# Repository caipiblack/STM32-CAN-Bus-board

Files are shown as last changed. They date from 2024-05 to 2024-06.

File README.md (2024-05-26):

STM32-CAN-Bus-board
-------------------

CAN Bus shield with external power supply (12V/24V) for NUCLEO-L432KC board.

All the pins of the NUCLEO-L432KC board are available on the connectors of the shield.

The available pins provide many peripherals (ADC, SPI, I2C, GPIO and more) that can be used for many projects (IOT sensors, security sensors, automation...)

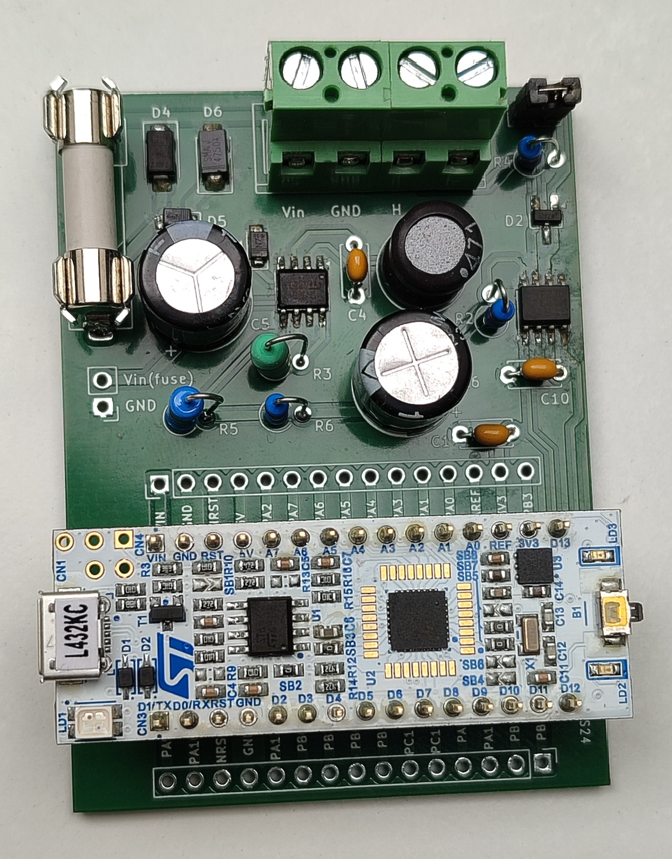
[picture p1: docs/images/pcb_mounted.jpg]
PCB Mounted


# Hardware

This part describe how the schematic was made, how to mount the PCB and how to test it.

**IMPORTANT: This shield require some modifications on the Nucleo board to works (due to external supply) (see after)**

## Kicad project

The Kicad project as been created with the version 8.0.1 of Kicad.

Most of the symbols and footprints comes from the default libraries.

The custom footprints are stored in the `custom` folder near the Kicad project.

Setup Kicad on Ubuntu 24.04:

```
sudo add-apt-repository ppa:kicad/kicad-8.0-releases
sudo apt update
sudo apt install kicad
```

The last production files are stored in the directory [hardware/rev_a/fab](hardware/rev_a/fab).

## Configuration of the NUCLEO-L432KC board

Some modifications are required to be able to power the Nucleo board from external 3V3 regulator (provided by the shield):
- Remove the jumper!
- Remove SB9.
- Remove SB14.

After these changes:
- The 3V3 power for the STM32 will be provided by "external power source" (the shield).
- The debug/flash side of Nucleo board will not be powered by the "external power source" (the shield).
- To flash or debug the Nucleo board, the Nucleo board must be connected by USB to the computer (The St-Link chip will be powered by 5V>3V regulator in the Nucleo board) AND the 3V3 power must be supplied by the shield (to power the STM32 chip).

## PCB mounting instructions

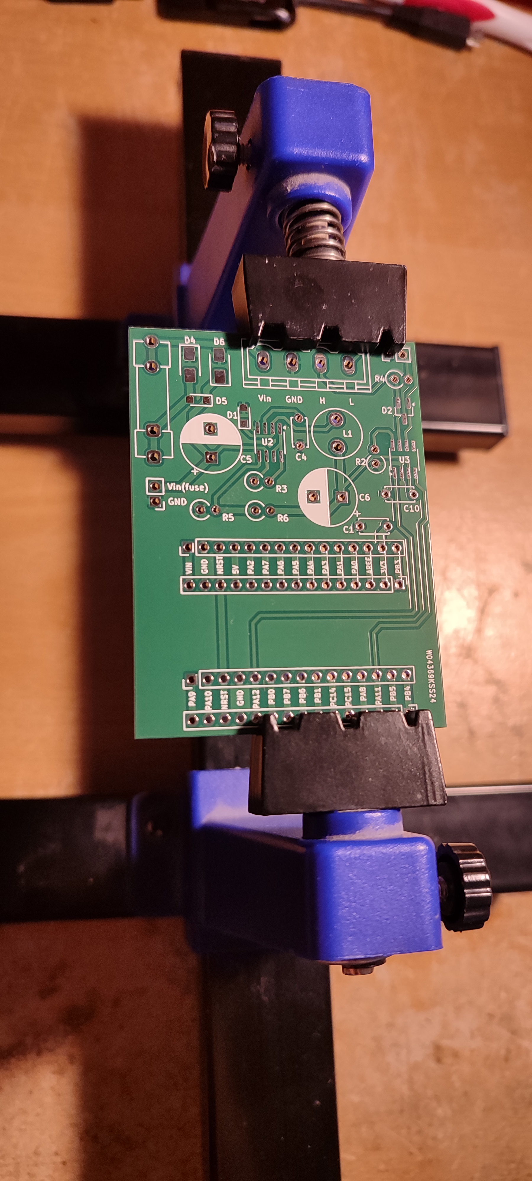
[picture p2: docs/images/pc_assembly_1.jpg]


Mount the components on the board:
1. Take the PCB and fix it to the table.
2. Put solder past on all CMS pads.
3. Configure your hot air machine with something like this:
- Speed: 3/8.
- Temperature: 300°C.
4. Solder the CMS components in this order: D4, D6, D1, D5, D2, U2, U3.
5. Solder the other components in this order: C1, C10, C4, R4, R2, R6, R3, R5, F1, Jumper, C6, C5, L1.
6. Mount the `NUCLEO-L432KC` board in the headers and solder the headers to the PCB (Doing it like this prevent issues with headers that are not perfectly vertical or parallel).
7. Remove the nucleo board from the soldered headers.

## PCB testing instructions

Testing instructions:
- Remove the `NUCLEO-L432KC` board from the headers.
- Power on the board with laboratory power supply configured at 12V with current limited to 50mA.
  - At this point the power consumption (on 12V line) should be less than 10mA.
  - Measure the voltage in the 3V3 pin and check that the voltage is around 3.3V.
- If the previous tests pass, turn off the power and plug the `NUCLEO-L432KC` board in the headers then turn on the power.
  - At this point the power consumption (on 12V line) should be less than 10mA.
- If the previous tests pass, connect the `NUCLEO-L432KC` board to the computer and flash it with the template project.
- Test the CAN interface:
  - Plug a USB<>CAN device from a Linux computer to the board.
  - On the computer, execute these commands:
```
sudo apt-get install can-utils
sudo modprobe vcan
sudo ip link add dev can0 type vcan
sudo ip link set up can0 type can bitrate 250000
candump -td -a can0
```
  - Reset the board
  - On the `candump` you should see something like this:
```
 (000.000000)  can0  71D   [1]  00                        '.'
```

# Software

This repository comes with a demo software in the `software` directory: This software act like a CANopen node and permits to control the LED of the `NUCLEO-L432KC` board.

This guide also describe how to create a project from scratch for the `STM32-CAN-Bus-board` board.

The LED can be controlled by writing in the object at index `0x6001`. (See examples at `CANopenLinux` section).

## Tools setup

1. Download and install `STM32CubeIDE` from [here](https://www.st.com/en/development-tools/stm32cubeide.html)
2. (Optional) Download and install `STM32CubeProg` from [here](https://www.st.com/en/development-tools/stm32cubeprog.html). (This tool can be used to only flash the `NUCLEO-L432KC` board without the IDE)

### Compatibility issues of STM32CubeIDE with Ubuntu 24.04

There are issues with `STM32CubeIDE` on `Ubuntu 24.04` because it has a dependecy to `libncurses5` and this is not available with this version of Ubuntu.

This dependency is required by the `arm-none-eabi-gdb` provided by ST.

To resolve the problem:
- Install the generic linux version of `STM32CubeIDE` instead of the version from `.deb` (as it will not check the dependency).
- Install `arm-none-eabi-gdb` or `gdb-multiarch` and create a link to provide `arm-none-eabi-gdb`:
```
sudo apt install gdb-multiarch
sudo ln -s /usr/bin/gdb-multiarch /usr/bin/arm-none-eabi-gdb
```
- In your project configuration `Project Properties -> C/C++ Build -> Environment -> PATH` add `/usr/bin` at the first place to use `arm-none-eabi-gdb` provided by `/usr/bin` instead of ST directories.

## Create a project from scratch

Base project creation:
1. Open `STM32CubeIDE`.
2. Press `File > New > STM32 Project`.
3. Press `Board Selector`.
4. Search `Commercial Part Number` with `NUCLEO-L432KC`, then select it and press Next
5. Specify the `Project Name` and `Location`, then press `Finish`.
6. Configure the peripheral in defaults state and open the configuration tool (or open `.ioc` file).
7. Change the configuration of `PA0` to `Reset_State` as we don't have MCO clock source when the `NUCLEO-L432KC` is externaly powered from 3V3 (because MCO comes from the St-Link chip and it is not powered in this situation).
8. In `Clock Configuration`:
- Select `System Clock Mux` to use `PLLCLK`
- Select `PLL Source Mux` to `MSI`
- Configure the PLL with `X48` and `/4` to get 48Mhz in SYSCLK and APBs

For the integration of `CANopenNode` stack see the README of [CanOpenSTM32](https://github.com/CANopenNode/CanOpenSTM32):
1. From configuration tool configure the CAN interface:
- Activate `CAN1`
- Activate all the interrupts of `CAN1`
- Enable `Automatic Bus-Off Management`
- Enable `Automatic Wake-Up Mode`
- Enable `Automatic Retransmission`
- Configure the Bit timing parameters, you can use [this generator](http://www.bittiming.can-wiki.info/). The clock for `CAN1` is `APB1` (datasheet). In my case with a clock of 48Mhz and desired bitrate of 250Kbit/s I set:
  - Prescaler: 12
  - Time Quanta in Bit Segment 1: 13 Times
  - Time Quanta in Bit Segment 2: 2 Times
2. From configuration tool configure a timer for `CANopenNode` stack:
- Activate `TIM16`
- Enable the interrupt of `TIM16`
- Configure `TIM16` to get 1ms. Note that `TIM16` use `APB2` clock. In my case with a clock of 48Mhz I set:
  - Prescaler (PSC - 16 bits value): 48-1
  - Counter Period (AutoReload Register - 16 bits value ): 1000-1
3. Clone `CanOpenSTM32` somewhere in your computer [see here](https://github.com/CANopenNode/CanOpenSTM32)
4. Take `CANopenNode` and `CANopenNode_STM32` directories from the cloned repo and copy that in your project (from the IDE)
5. Add `CANopenNode` and `CANopenNode_STM32` to `Source locations` in `Project Properties -> C/C++ General -> Paths and Symbols -> Source Locations`. Then add an exclusion filter for `example/` folder for `CANopenNode` folder
6. Add `CANopenNode` and `CANopenNode_STM32` to `Project Properties -> C/C++ General -> Paths and Symbols -> Includes` under `GNU C` items
7. In your `main.c`, add `#include "CO_app_STM32.h"`:
```
/* Private includes ----------------------------------------------------------*/
/* USER CODE BEGIN Includes */
#include "CO_app_STM32.h"
/* USER CODE END Includes */
```
8. In the `main.c` file, call `canopen_app_interrupt()` when the timer ticks at 1ms:
```
/* USER CODE BEGIN 4 */
void HAL_TIM_PeriodElapsedCallback(TIM_HandleTypeDef *htim) {
	  // Handle CANOpen app interrupts
	  if (htim == canopenNodeSTM32->timerHandle) {
	      canopen_app_interrupt();
	  }
}
/* USER CODE END 4 */
```
9. In the `main.c` file, configure the `CANopenNode` stack and call the `canopen_app_process()` function in the main loop:
```
int main(void)
{
  // ...

  /* Initialize all configured peripherals */
  // ...
  /* USER CODE BEGIN 2 */
  CANopenNodeSTM32 canOpenNodeSTM32;
  canOpenNodeSTM32.CANHandle = &hcan1;
  canOpenNodeSTM32.HWInitFunction = MX_CAN1_Init;
  canOpenNodeSTM32.timerHandle = &htim16;
  canOpenNodeSTM32.desiredNodeID = 20;
  canOpenNodeSTM32.baudrate = 250;
  canopen_app_init(&canOpenNodeSTM32);
  /* USER CODE END 2 */

  /* Infinite loop */
  /* USER CODE BEGIN WHILE */
  while (1)
  {
    /* USER CODE END WHILE */

    /* USER CODE BEGIN 3 */
	  canopen_app_process();
  }
  /* USER CODE END 3 */
}
```
10. Flash the board and execute the CAN tests described in `PCB testing instructions`.

## Configure the object dictionary

1. Find the last release of `CANopenEditor` and download the binaries [link](https://github.com/CANopenNode/CANopenEditor/releases)
2. Extract the release binary archive
3. Open `EDSEditor.exe` with wine:
```
wine net481/EDSEditor.exe
```
4. Open the file `CANopenNode_STM32/DS301_profile.xpd`

## CANopenLinux

CANopenLinux can be used as a gateway to communicate with CANopen devices using socket/stdio commands.

Setup the CAN interface:
```
sudo apt-get install can-utils
sudo modprobe vcan
# Do it only if can0 is not already mounted!
#sudo ip link add dev can0 type vcan
sudo ip link set up can0 type can bitrate 250000
```

Download and install CANopenLinux:
```
git clone https://github.com/CANopenNode/CANopenLinux.git
cd CANopenLinux
git submodule update --init --recursive
make
```

Read an OD entry from the computer:
```
./canopend can0 -i 1 -c "stdio"
20 r 0x1000 0
[0] 34 12 00 00
```

Write an OD entry from the computer:
```
./canopend can0 -i 1 -c "stdio"
20 w 0x6001 0 U32 0
[0] OK
```

_In my example, 0x6001 controls the LED!_

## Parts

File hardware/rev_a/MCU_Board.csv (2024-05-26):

Reference | Value | Datasheet | Footprint | Qty | DNP
C1,C10 | 100n | https://fr.farnell.com/kemet/c322c104m5u5ta/condensateur-0-1-f-50v-20-z5u/dp/1457707 | Capacitor_THT:C_Disc_D5.0mm_W2.5mm_P5.00mm | 2
C4 | 680p | https://fr.farnell.com/vishay/k681k10x7rf5uh5/condensateur-680pf-50v-mlcc-radial/dp/3289410 | Capacitor_THT:C_Disc_D5.0mm_W2.5mm_P5.00mm | 1
C5 | 100u | https://fr.farnell.com/teapo/ksh107m063s1a5h12k/condensateur-100-f-63v-20/dp/2800122 | Capacitor_THT:CP_Radial_D10.0mm_P5.00mm | 1
C6 | 1000u | https://fr.farnell.com/multicomp/mcksk010m102g13s/condensateur-1000-f-10v-20/dp/2610799 | Capacitor_THT:CP_Radial_D10.0mm_P5.00mm | 1
D1 | PMEG4020CERX | https://fr.farnell.com/nexperia/pmeg4020cerx/diode-schottky-40v-2a-cfp3/dp/4313202 | Diode_SMD:Nexperia_CFP3_SOD-123W | 1
D2 | SM24CANB-02HTG | https://fr.farnell.com/littelfuse/sm24canb-02htg/diode-protection-esd-aec-q101/dp/2749174 | Package_TO_SOT_SMD:SOT-23_Handsoldering | 1
D4 | SMAJ33CA | https://fr.farnell.com/littelfuse/smaj33ca/diode-tvs-400w-33v-bidir-do-214ac/dp/2691544?st=smaj33ca | Diode_SMD:D_SMA | 1
D5 | PMEG6020CER | https://fr.farnell.com/nexperia/pmeg6020cer-qx/diode-schottky-60v-2a-cfp3/dp/4313204 | Diode_SMD:Nexperia_CFP3_SOD-123W | 1
D6 | SMAJ4750A | https://fr.farnell.com/multicomp/smaj4750a/diode-zener-1w-27v-do-214ac/dp/2675213 | Diode_SMD:D_SMA | 1
F1 | Fuse | https://fr.farnell.com/multicomp-pro/mp008633/fusible-cartouche-act-rapide-0/dp/3873902?ost=mp008633 | Fuse:Fuseholder_Clip-5x20mm_Littelfuse_100_Inline_P20.50x4.60mm_D1.30mm_Horizontal | 1
J1,J5,J6,J7 | Conn_01x15 | ~ | Connector_PinHeader_2.54mm:PinHeader_1x15_P2.54mm_Vertical | 4
J2 | Conn_01x02 | ~ | Connector_PinHeader_2.54mm:PinHeader_1x02_P2.54mm_Vertical | 1
J3 | Bus | https://fr.farnell.com/camdenboss/ctbp0158-2/bornier-fil-a-carte-2-voies-12awg/dp/3228568 | custom:PhoenixContact_MSTBVA_2,5_4-G-5,08_1x04_P5.08mm_Vertical_custom | 1
JP1 | Jumper_2_Open | ~ | Connector_PinHeader_2.54mm:PinHeader_1x02_P2.54mm_Vertical | 1
L1 | 470u | https://fr.farnell.com/bourns/rlb0914-471kl/inductor-470uh/dp/2309247 | Inductor_THT:L_Radial_D8.7mm_P5.00mm_Fastron_07HCP | 1
R2,R6 | 10k | https://fr.farnell.com/yageo/mfr50sfte52-10k/res-10k-1-0-5w-axial-couche-metal/dp/3496944 | Resistor_THT:R_Axial_DIN0309_L9.0mm_D3.2mm_P2.54mm_Vertical | 2
R3 | 0R33 | https://fr.farnell.com/multicomp/mcknp01sj033ka10/resistance-bobinee-0r33-5-1ws/dp/1903702 | Resistor_THT:R_Axial_DIN0309_L9.0mm_D3.2mm_P2.54mm_Vertical | 1
R4 | 120 | https://fr.farnell.com/yageo/mfr50sfte52-120r/res-120r-0-5w-axial-couche-metal/dp/3496947 | Resistor_THT:R_Axial_DIN0309_L9.0mm_D3.2mm_P2.54mm_Vertical | 1
R5 | 6k2 | https://fr.farnell.com/multicomp/mf50-6k2/resistance-0-5w-1-6k2/dp/9340785 | Resistor_THT:R_Axial_DIN0309_L9.0mm_D3.2mm_P2.54mm_Vertical | 1
U2 | MC34063AD | https://fr.farnell.com/stmicroelectronics/mc34063ebd-tr/convertisseur-dc-dc-buck-boost/dp/3367118?st=mc34063 | Package_SO:SOIC-8_3.9x4.9mm_P1.27mm | 1
U3 | SN65HVD230 | https://fr.farnell.com/texas-instruments/sn65hvd230dr/ic-can-transceiver-1mbps-8soic/dp/3124671 | Package_SO:SOIC-8_3.9x4.9mm_P1.27mm | 1

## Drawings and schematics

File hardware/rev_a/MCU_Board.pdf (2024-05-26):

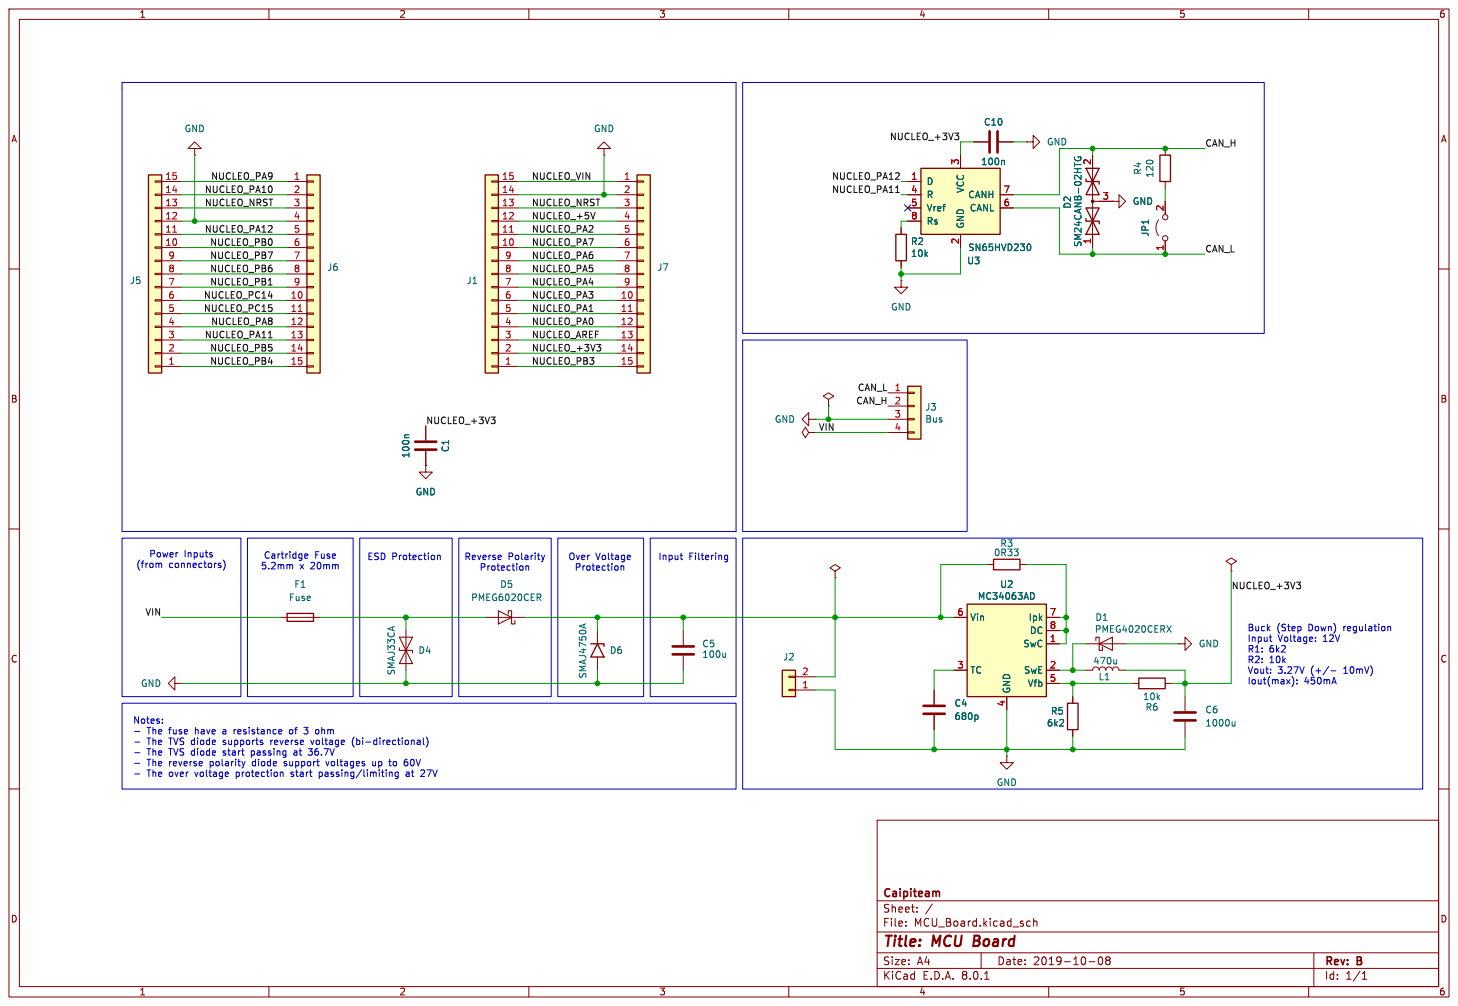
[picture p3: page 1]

- The TVS diode start passing at 36.7V

Id: 1/1 Title: MCU Board

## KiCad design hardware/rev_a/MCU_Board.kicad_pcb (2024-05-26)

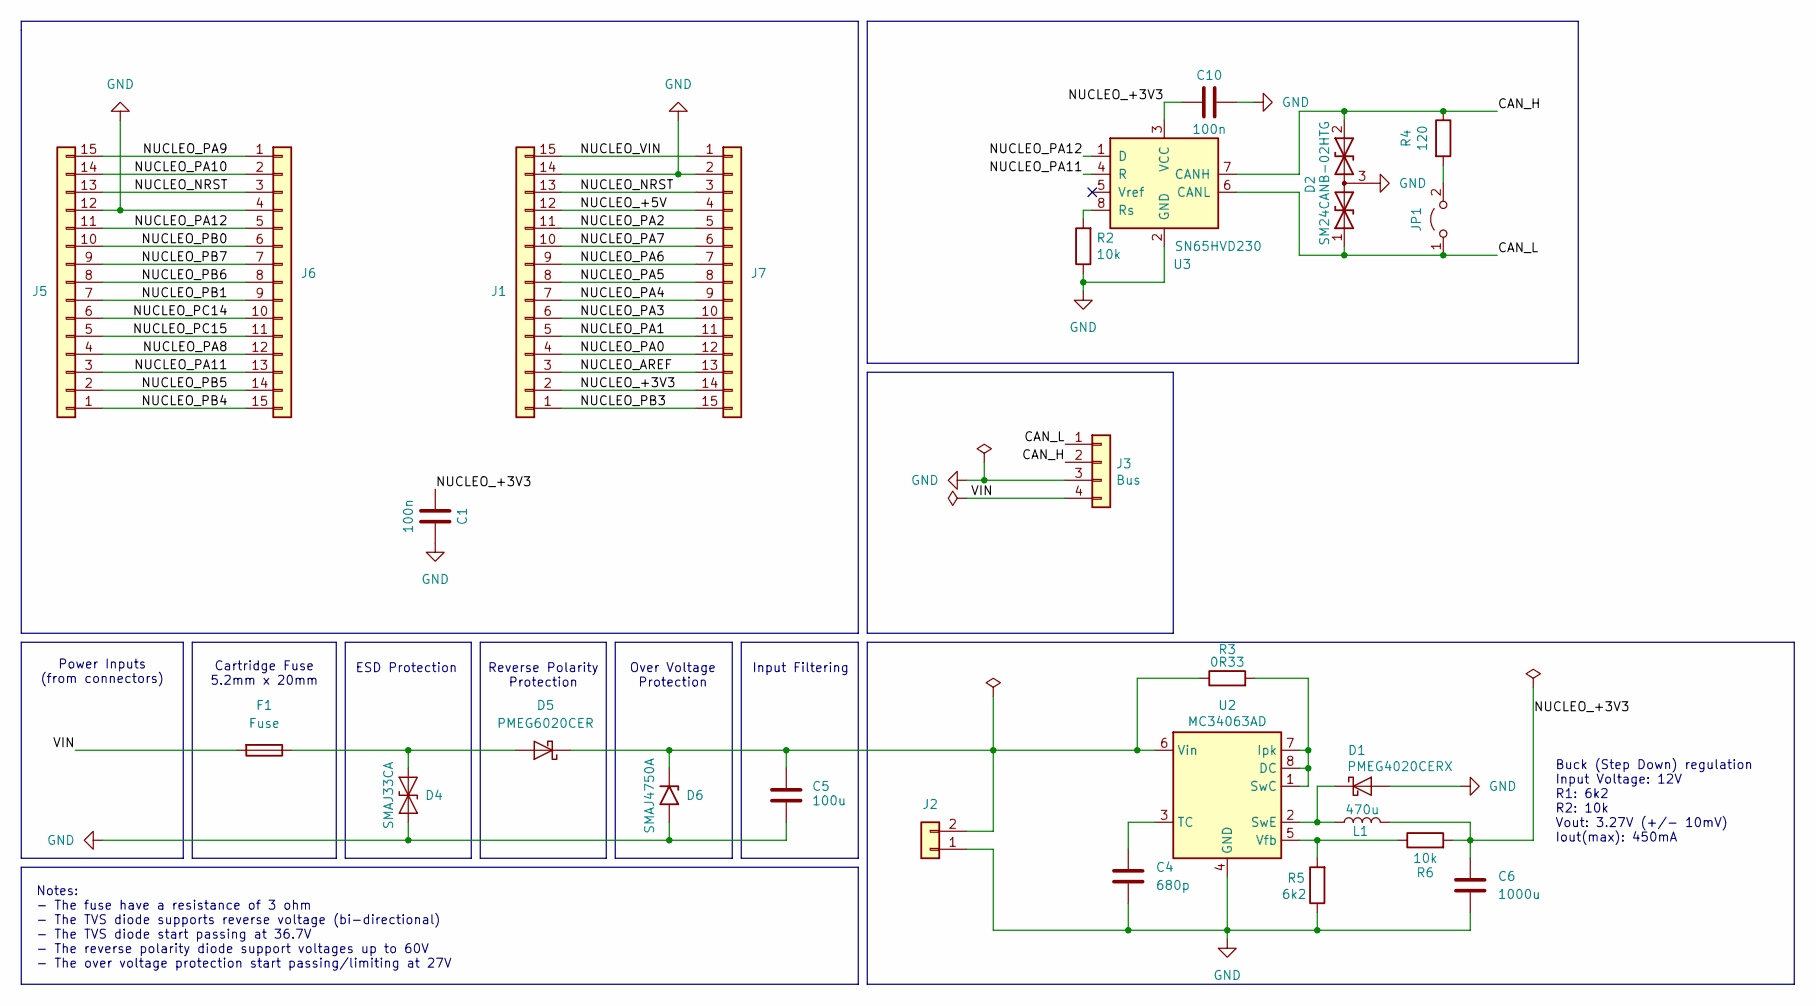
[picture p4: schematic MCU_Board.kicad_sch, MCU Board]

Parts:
C1, C10: 100n; C_Disc_D5.0mm_W2.5mm_P5.00mm
C4: 680p; C_Disc_D5.0mm_W2.5mm_P5.00mm
C5: 100u; CP_Radial_D10.0mm_P5.00mm
C6: 1000u; CP_Radial_D10.0mm_P5.00mm
D1: PMEG4020CERX; Nexperia_CFP3_SOD-123W
D2: SM24CANB-02HTG; SOT-23_Handsoldering
D4: SMAJ33CA; D_SMA
D5: PMEG6020CER; Nexperia_CFP3_SOD-123W
D6: SMAJ4750A; D_SMA
F1: Fuse; Fuseholder_Clip-5x20mm_Littelfuse_100_Inline_P20.50x4.60mm_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
J1, J5, J6, J7: Conn_01x15; PinHeader_1x15_P2.54mm_Vertical
J2: Conn_01x02; PinHeader_1x02_P2.54mm_Vertical
J3: Bus; PhoenixContact_MSTBVA_2,5_4-G-5,08_1x04_P5.08mm_Vertical_cu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
JP1: Jumper_2_Open; PinHeader_1x02_P2.54mm_Vertical
L1: 470u; L_Radial_D8.7mm_P5.00mm_Fastron_07HCP
R2, R6: 10k; R_Axial_DIN0309_L9.0mm_D3.2mm_P2.54mm_Vertical
R3: 0R33; R_Axial_DIN0309_L9.0mm_D3.2mm_P2.54mm_Vertical
R4: 120; R_Axial_DIN0309_L9.0mm_D3.2mm_P2.54mm_Vertical
R5: 6k2; R_Axial_DIN0309_L9.0mm_D3.2mm_P2.54mm_Vertical
U2: MC34063AD; SOIC-8_3.9x4.9mm_P1.27mm
U3: SN65HVD230; SOIC-8_3.9x4.9mm_P1.27mm

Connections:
/CAN_H: D2.2 (A2), J3.2, R4.1, U3.7 (CANH)
/CAN_L: D2.1 (A1), J3.1, JP1.1 (A), U3.6 (CANL)
/NUCLEO_+3V3: C1.2, C6.1, C10.2, J1.2, J7.14, L1.2, R6.2, U3.3 (VCC)
/NUCLEO_+5V: J1.12, J7.4
/NUCLEO_AREF: J1.3, J7.13
/NUCLEO_NRST: J1.13, J5.13, J6.3, J7.3
/NUCLEO_PA0: J1.4, J7.12
/NUCLEO_PA1: J1.5, J7.11
/NUCLEO_PA2: J1.11, J7.5
/NUCLEO_PA3: J1.6, J7.10
/NUCLEO_PA4: J1.7, J7.9
/NUCLEO_PA5: J1.8, J7.8
/NUCLEO_PA6: J1.9, J7.7
/NUCLEO_PA7: J1.10, J7.6
/NUCLEO_PA8: J5.4, J6.12
/NUCLEO_PA9: J5.15, J6.1
/NUCLEO_PA10: J5.14, J6.2
/NUCLEO_PA11: J5.3, J6.13, U3.4 (R)
/NUCLEO_PA12: J5.11, J6.5, U3.1 (D)
/NUCLEO_PB0: J5.10, J6.6
/NUCLEO_PB1: J5.7, J6.9
/NUCLEO_PB3: J1.1, J7.15
/NUCLEO_PB4: J5.1, J6.15
/NUCLEO_PB5: J5.2, J6.14
/NUCLEO_PB6: J5.8, J6.8
/NUCLEO_PB7: J5.9, J6.7
/NUCLEO_PC14: J5.6, J6.10
/NUCLEO_PC15: J5.5, J6.11
/NUCLEO_VIN: J1.15, J7.1
/VIN: F1.2, J3.4
GND: C1.1, C4.2, C5.2, C6.2, C10.1, D1.2 (A), D2.3 (common), D4.1 (A1), D6.2 (A2), J1.14, J2.1, J3.3, J5.12, J6.4, J7.2, R2.1, R5.1, U2.4 (GND), U3.2 (GND)
unnamed: D1.1 (K), L1.1, U2.2 (SwE)
unnamed: D4.2 (A2), D5.2 (A), F1.1
unnamed: C5.1, D5.1 (K), D6.1 (A1), J2.2, R3.1, U2.6 (Vin)
unnamed: JP1.2 (B), R4.2
unnamed: R3.2, U2.1 (SwC), U2.7 (Ipk), U2.8 (DC)
unnamed: C4.1, U2.3 (TC)
unnamed: R5.2, R6.1, U2.5 (Vfb)
unnamed: R2.2, U3.8 (Rs)

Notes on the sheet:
Reverse Polarity Protection
Over Voltage Protection
ESD Protection
Input Filtering
Cartridge Fuse 5.2mm x 20mm
Notes: - The fuse have a resistance of 3 ohm - The TVS diode supports reverse voltage (bi-directional) - The TVS diode start passing at 36.7V - The reverse polarity diode support voltages up to 60V - The over voltage protection start passing/limiting at 27V
Power Inputs (from connectors)
Buck (Step Down) regulation Input Voltage: 12V R1: 6k2 R2: 10k Vout: 3.27V (+/- 10mV) Iout(max): 450mA

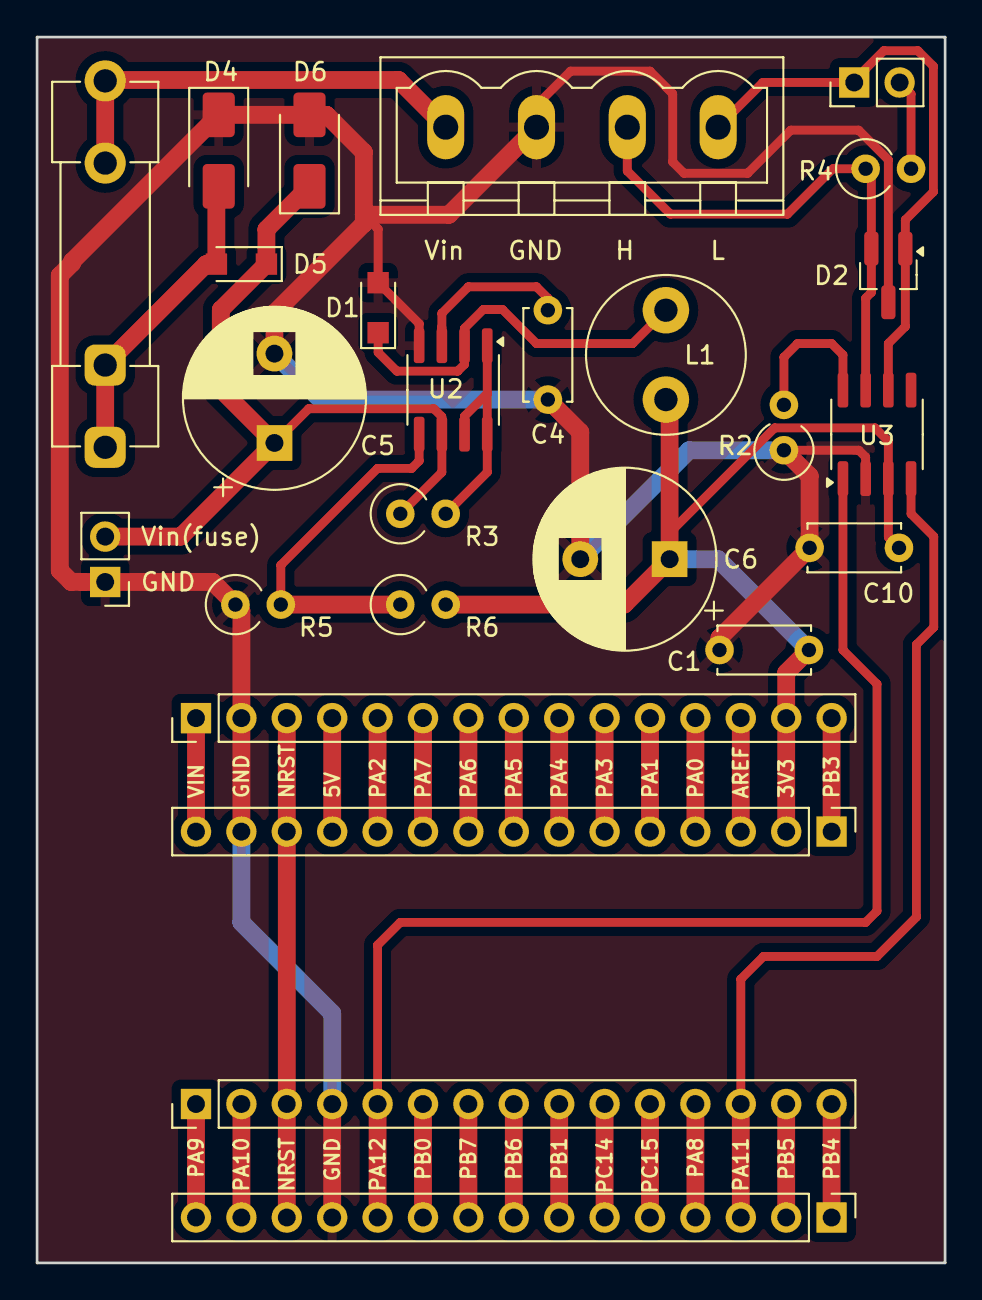
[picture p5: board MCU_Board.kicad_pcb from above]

Board: 2 copper layers, 50.8 x 68.6 mm, 26 parts (0 on the bottom side), 39 nets.

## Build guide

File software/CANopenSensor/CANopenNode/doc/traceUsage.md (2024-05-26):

Trace usage
===========

**TRACE DOES NOT WORK IN THE LAST VERSION**

CANopenNode includes optional trace functionality (non-standard). It monitors
choosen variables from Object Dictionary. On change of state of variable it
makes a record with timestamp into circular buffer. String with points can later
be read via SDO.

Trace is disabled by default. It can be enabled using Object Dictionary editor.
Include also *CO_trace.h/.c* into project, compile and run.

Here is en example of monitoring variable, connected with buttons
(OD_readInput8Bit, index 0x6000, subindex 0x01). It was tested on PIC32:

```
# Enable trace first:
./canopencomm 0x30 w 0x2400 0 u8 1

# Press and hold the button on Explorer16 and execute SDO read command:
./canopencomm 0x30 r 0x6000 1 u8
[1] 0x08
# It displays same value, as was transmitted via PDO and visible on candump.

# Now get the complete history for that buttons with timestamp for each change
# and store it as a text to the file:
./canopencomm 0x30 r 0x2401 5 vs > plot1.csv
cat plot1.csv
```
If large data blocks are transmitted via CAN bus, then more efficient SDO block
transfer can be enabled with command `./canopencomm set sdo_block 1`

For more info on using trace functionality see CANopenNode/example/IO.html
file. There is also a description of all Object Dictionary variables.

Trace functionality can also be configured on CANopenSocket directly. In that
case CANopenSocket must first receive PDO data from remote node(s) and store it
to the local Object Dictionary variable. CANopenSocket's trace then monitors
that variable. Text buffer is then read with the similar command as above. But
local SDO data access from CANopenSocket itself doesn't occupy CAN bus, so large
data is transfered realy fast. Besides that, Linux machine has much more RAM to
store the monitored data. Except timestamp is less accurate.

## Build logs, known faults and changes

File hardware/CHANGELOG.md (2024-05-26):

# Changelog

All notable changes to this project will be documented in this file.

The format is based on [Keep a Changelog](https://keepachangelog.com/en/1.0.0/),
and this project adheres to [Semantic Versioning](https://semver.org/spec/v2.0.0.html).

## [Unreleased]

### Added

### Changed

### Deprecated

### Removed

### Fixed

### Security

## [rev A] - 2024-05-26

### Added

- Creation of the project

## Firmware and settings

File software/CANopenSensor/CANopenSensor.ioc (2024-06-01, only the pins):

Mcu.UserName=STM32L432KCUx
PA11.Signal=CAN1_RX
PA12.Signal=CAN1_TX
PA2.GPIO_Label=VCP_TX
PA2.Signal=USART2_TX
PA4.GPIO_Label=GPIO_Mouvement
PA4.Signal=GPXTI4
PA5.GPIO_Label=GPIO_Vibration
PA5.Signal=GPXTI5
PA6.GPIO_Label=PWM_Buzzer
PA6.Signal=S_TIM16_CH1

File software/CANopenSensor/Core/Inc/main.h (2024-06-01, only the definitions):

#define VCP_TX_Pin GPIO_PIN_2
#define VCP_TX_GPIO_Port GPIOA
#define GPIO_Mouvement_Pin GPIO_PIN_4
#define GPIO_Mouvement_GPIO_Port GPIOA
#define GPIO_Mouvement_EXTI_IRQn EXTI4_IRQn
#define GPIO_Vibration_Pin GPIO_PIN_5
#define GPIO_Vibration_GPIO_Port GPIOA
#define GPIO_Vibration_EXTI_IRQn EXTI9_5_IRQn
#define PWM_Buzzer_Pin GPIO_PIN_6
#define PWM_Buzzer_GPIO_Port GPIOA
#define SWDIO_Pin GPIO_PIN_13
#define SWDIO_GPIO_Port GPIOA
#define SWCLK_Pin GPIO_PIN_14
#define SWCLK_GPIO_Port GPIOA
#define VCP_RX_Pin GPIO_PIN_15
#define VCP_RX_GPIO_Port GPIOA
#define LD3_Pin GPIO_PIN_3
#define LD3_GPIO_Port GPIOB

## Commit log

2024-05-26 1 kicad project creation (#2)
    Add the hardware project (+ build/test instructions) and a template software project.
    [MCU_Board-B_Cu.gbr, MCU_Board-B_Mask.gbr, MCU_Board-B_Paste.gbr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]
2024-06-01 Add an example of CANopen sensor
    [CANopenSensor Debug.cfg]
2024-06-01 Update the sensor example

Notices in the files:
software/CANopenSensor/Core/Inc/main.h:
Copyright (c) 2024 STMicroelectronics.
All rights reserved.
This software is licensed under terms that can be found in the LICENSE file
